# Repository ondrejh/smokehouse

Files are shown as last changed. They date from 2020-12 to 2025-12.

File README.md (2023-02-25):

# SmokeHouse

The IOT smokehouse thermometer using standard web server as the interface.

## Thermometer HW

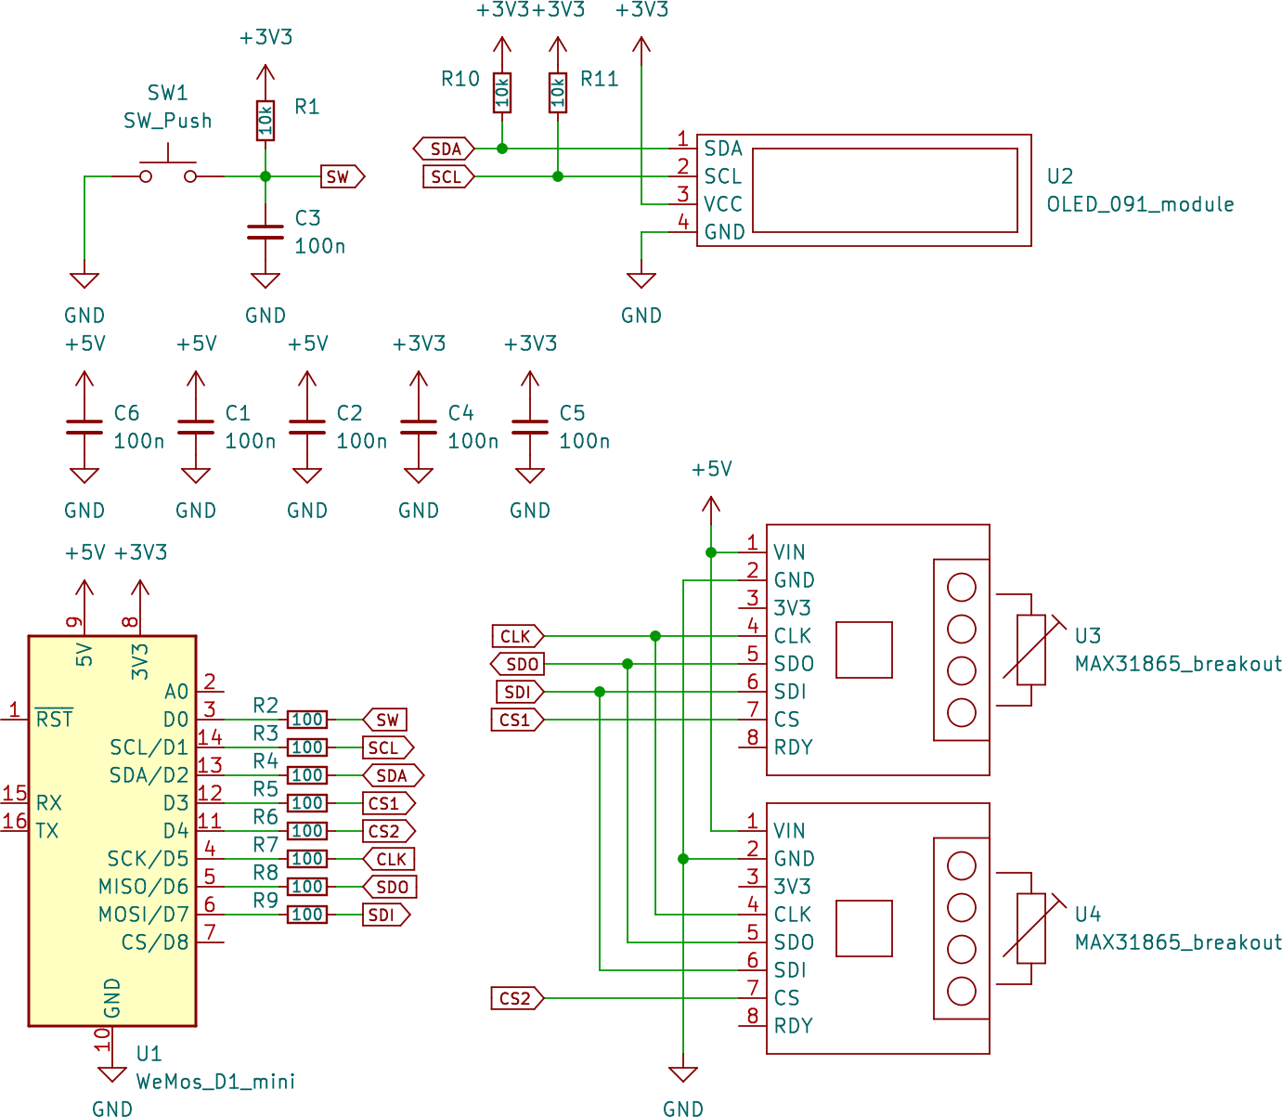
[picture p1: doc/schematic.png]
schematic

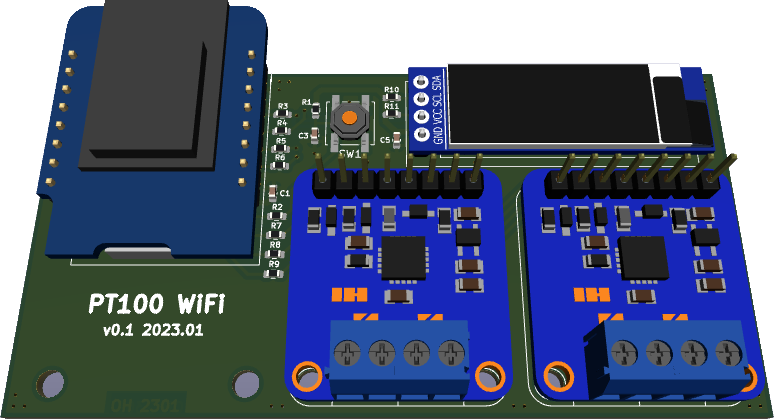
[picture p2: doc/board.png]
board


## DB scheme ##

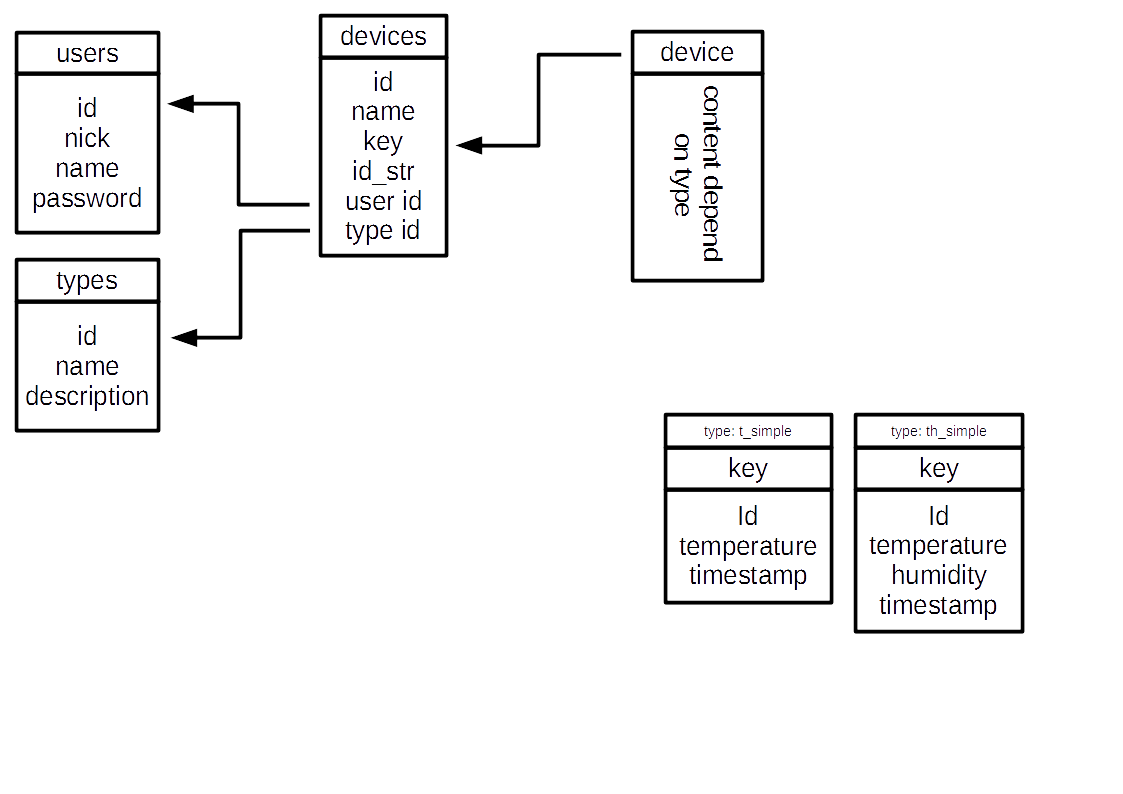
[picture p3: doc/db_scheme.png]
Database scheme


## Next steps (HW / FW) ##

- [X] use device registration (unique id, key)
- [X] add the second thermocoupler
- [X] draw schematic
- [X] design pcb
- [ ] oversampling
- [ ] assemble prototypes

## Next steps (WEBI) ##

- [X] limit data table length
- [X] keep time distances between rows
- [ ] consolidate folders
- [ ] build better local webi
- [ ] build better server webi

## Next steps (all)

- [ ] update docu

## Install LAMP ##

https://gist.github.com/ondrejh/c1df59c4e6e8c8cb88a95b12bdac447b#file-lamp_install-md

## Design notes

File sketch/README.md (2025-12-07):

# Compile and flash using arduino-cli

## Install arduino-cli

```
curl -fsSL https://raw.githubusercontent.com/arduino/arduino-cli/master/install.sh | sudo sh
```

## Compile

Compile **device** sketch using arduino-cli. Target board esp8266 **wemos d1 mini**. Output directory **build**.

```
arduino-cli compile --fqbn esp8266:esp8266:d1_mini --output-dir build device
```

## Flash

```
arduino-cli upload --fqbn esp8266:esp8266:d1_mini -p /dev/ttyUSB0 --input-file build/device.ino.bin
```

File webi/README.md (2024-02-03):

# Files

## Tree

|
|--- inc
|    |--- bootstrap.php
|    |--- config.php
|
|--- thing.php

## Description

inc/config.php: configuration, mainly DB credentials
inc/bootstrap.php: include files

thing.php: the endpoint for data exchange of iot devices

# Database

create database restapi;
use restapi;
create table `things` (`id` bigint(20) unsigned NOT NULL AUTO_INCREMENT, `name` varchar(60) collate utf8mb4_unicode_ci NOT NULL DEFAULT '', `key` varchar(100) collate utf8mb4_unicode_ci NOT NULL DEFAULT '', `data` JSON, PRIMARY KEY(`id`));
insert into things(`name`, `key`) values('test1234', '123456');

# Sources

[How to Build a Simple REST API in PHP](code.tutsplus.com/how-to-build-a-simple-rest-api-in-php--cms-37000t)
[How to Create Simple Rest API in PHP Framework: A Foundation Blueprint](boltic.io/blog/rest-api-in-php-framework)

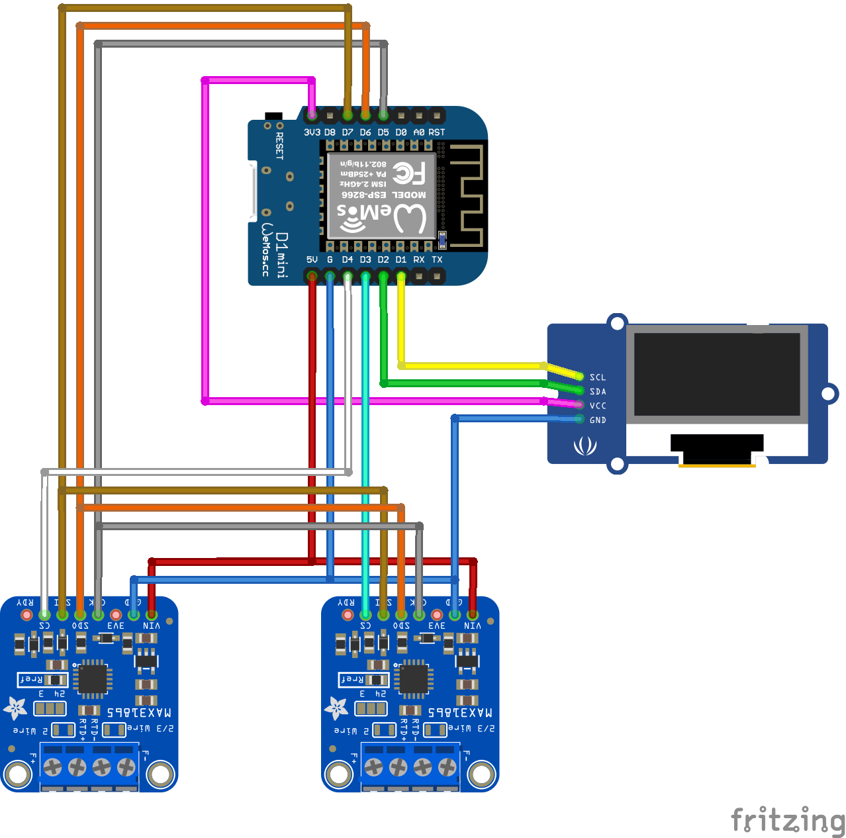
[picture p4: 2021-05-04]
doc/Udirna_2xPT100_bb.png

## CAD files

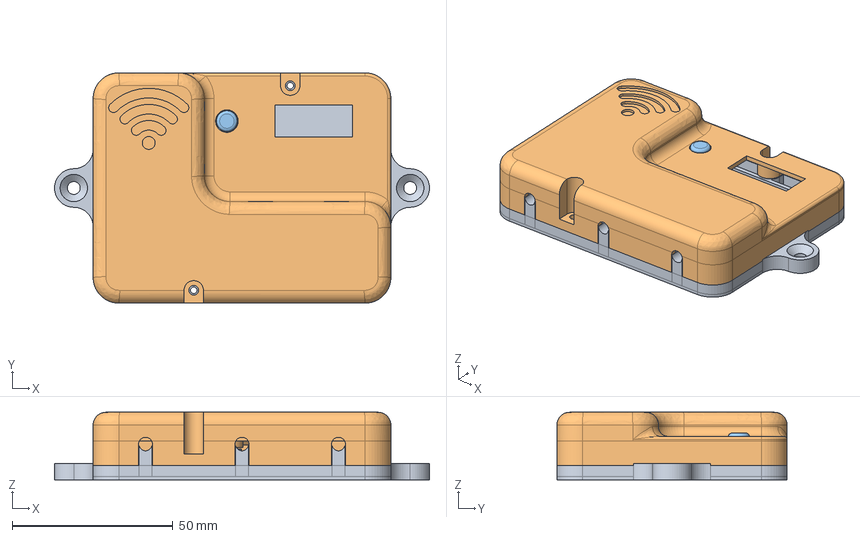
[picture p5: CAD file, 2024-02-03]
models/case.FCStd
116.6 x 71.6 x 21.0 mm
bottom
top
button

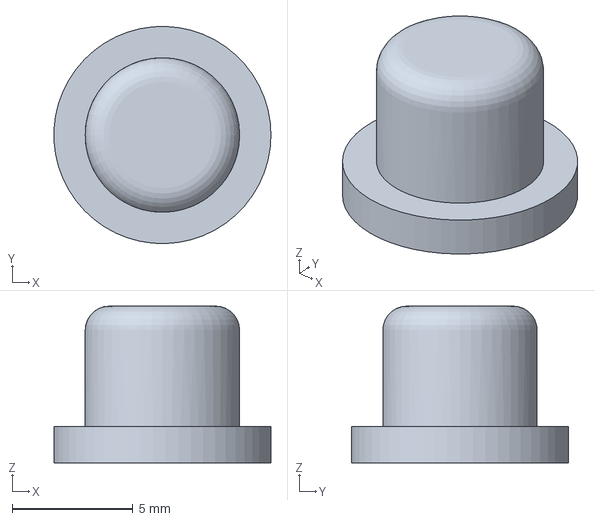
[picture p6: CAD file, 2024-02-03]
models/case-button.3mf
8.99 x 9.00 x 6.50 mm

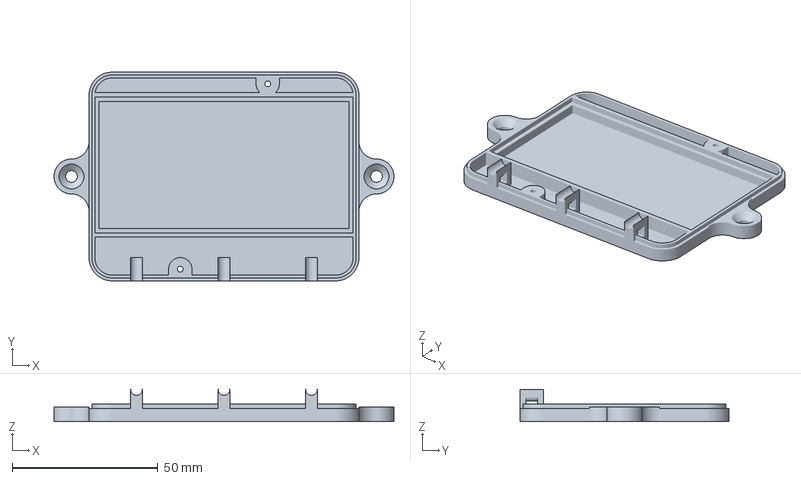
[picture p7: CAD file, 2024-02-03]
models/case-bottom.3mf
116.6 x 71.6 x 11.0 mm

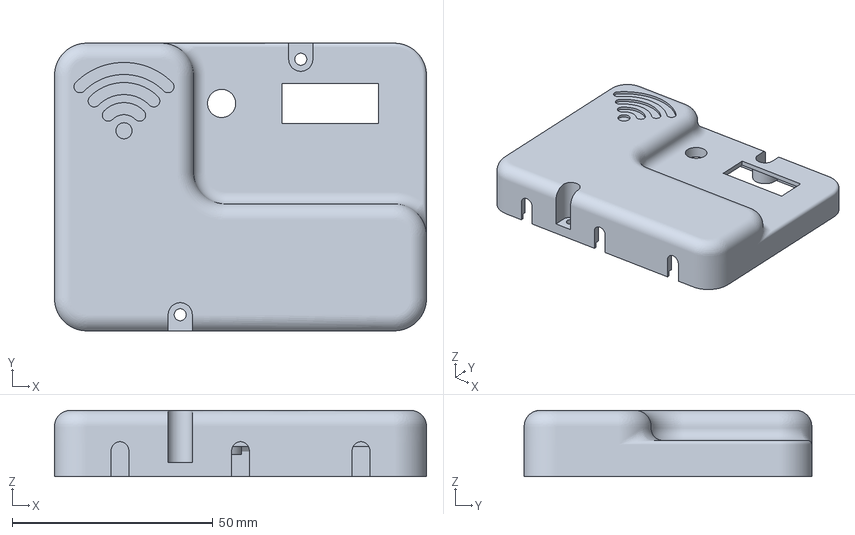
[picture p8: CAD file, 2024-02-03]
models/case-top.3mf
92.6 x 71.6 x 16.5 mm

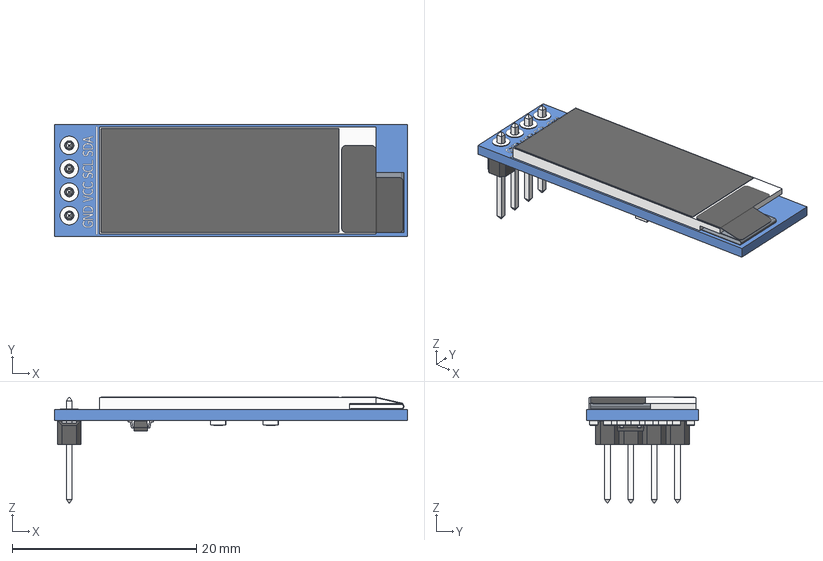
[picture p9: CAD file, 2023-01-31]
models/OLED_0.91_128x32.stp
38.3 x 12.1 x 11.5 mm
OLED_0.91_128x32
Pin Header 4 x 1 TH 2.54mm Pitch
RESC-0603 x 13
2SD0601A

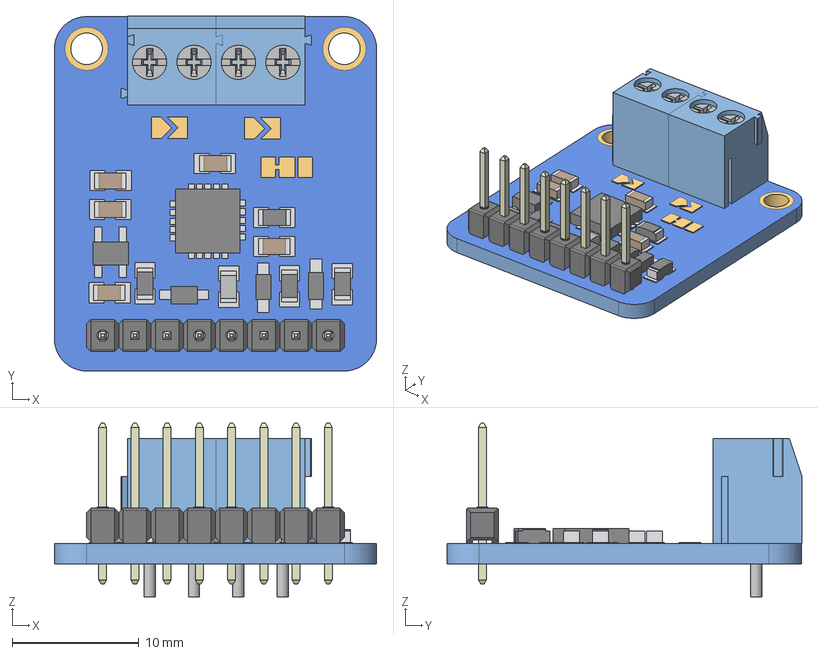
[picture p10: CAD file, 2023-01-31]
models/MAX31865.stp
25.4 x 28.0 x 13.7 mm
plytka
Pin Header 1x4 TH Pitch 2.54mm x 2
TE_1776275-2 x 2

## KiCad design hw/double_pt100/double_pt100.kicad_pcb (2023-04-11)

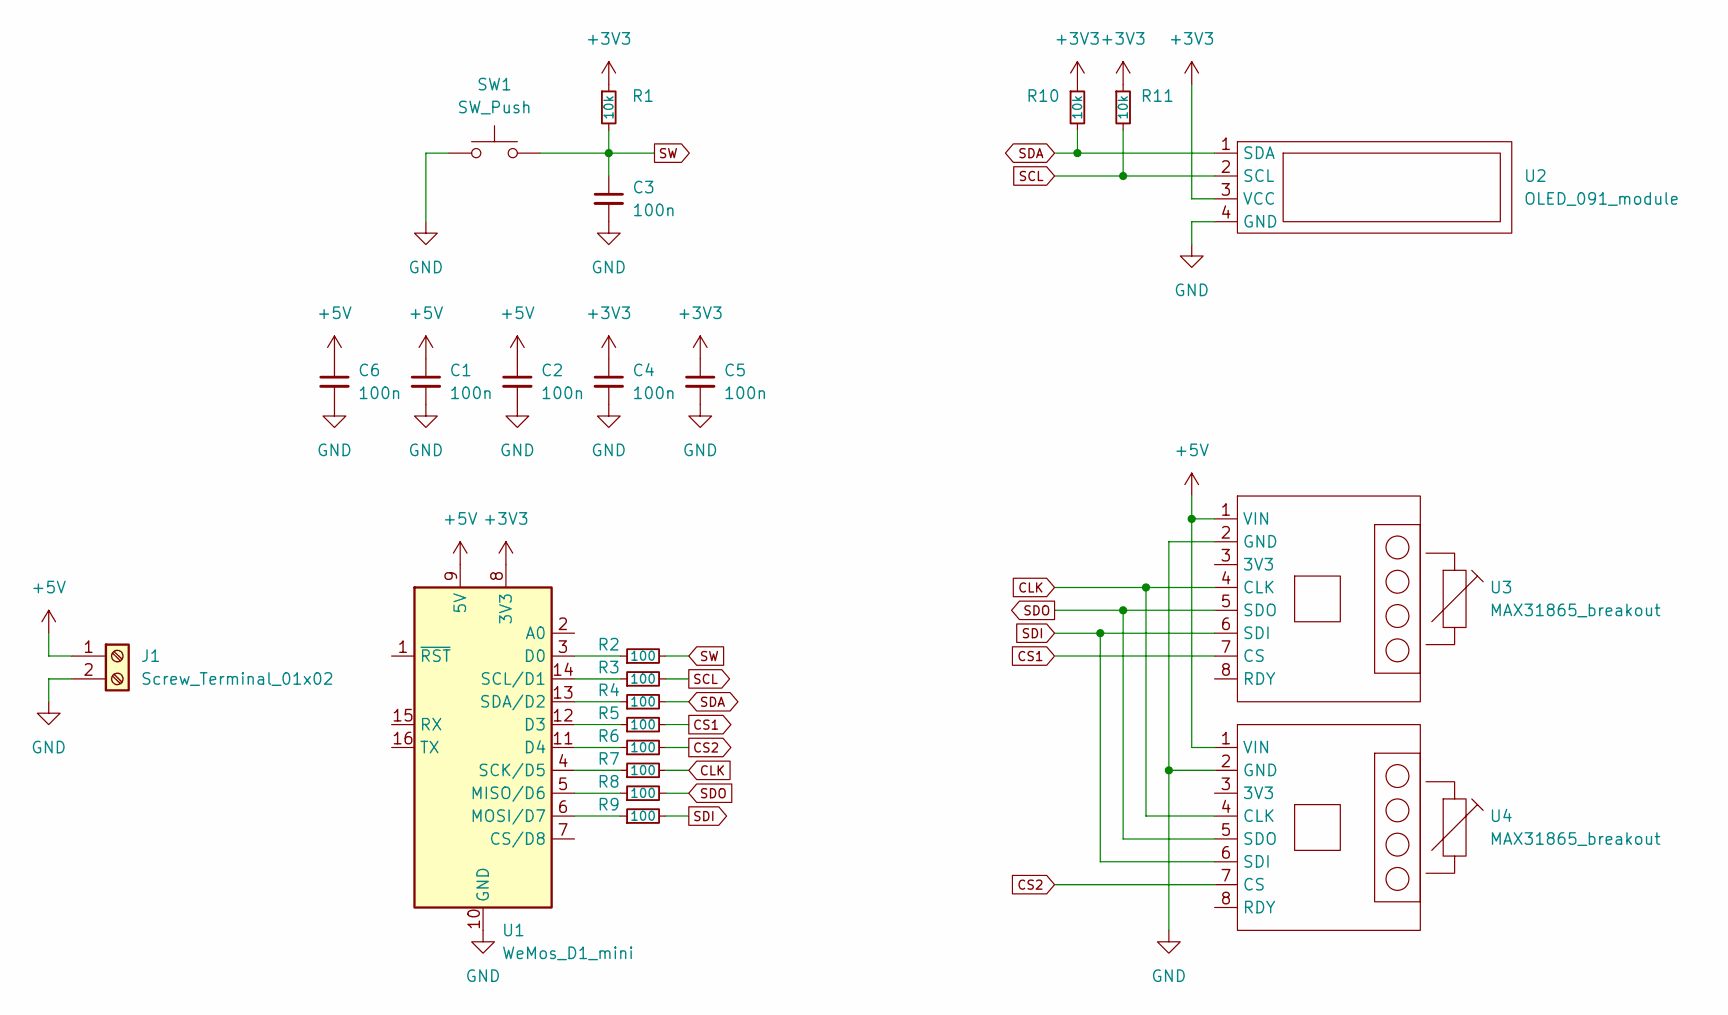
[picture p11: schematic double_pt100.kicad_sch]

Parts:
C1, C2, C3, C4, C5, C6: 100n; C_0603_1608Metric
J1: Screw_Terminal_01x02; TerminalBlock_Phoenix_PT-1,5-2-3.5-H_1x02_P3.50mm_Horizontal
R1, R10, R11: 10k; R_0603_1608Metric
R2, R3, R4, R5, R6, R7, R8, R9: 100; R_0603_1608Metric
SW1: SW_Push; SW_Push_1P1T_NO_CK_KSC6xxJ
U1: WeMos_D1_mini; WEMOS_D1_mini_light
U2: OLED_091_module
U3, U4: MAX31865_breakout; MAX31865_module

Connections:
+3V3: C4.1, C5.1, R1.1, R10.1, R11.1, U1.8 (3V3), U2.3 (VCC)
+5V: C1.1, C2.1, C6.1, J1.1, U1.9 (5V), U3.1 (VIN), U4.1 (VIN)
CLK: R7.2, U3.4 (CLK), U4.4 (CLK)
CS1: R5.2, U3.7 (CS)
CS2: R6.2, U4.7 (CS)
GND: C1.2, C2.2, C3.2, C4.2, C5.2, C6.2, J1.2, SW1.1, U1.10 (GND), U2.4 (GND), U3.2 (GND), U4.2 (GND)
unnamed: R2.1, U1.3 (D0)
unnamed: R3.1, U1.14 (SCL/D1)
unnamed: R4.1, U1.13 (SDA/D2)
unnamed: R5.1, U1.12 (D3)
unnamed: R6.1, U1.11 (D4)
unnamed: R7.1, U1.4 (SCK/D5)
unnamed: R8.1, U1.5 (MISO/D6)
unnamed: R9.1, U1.6 (MOSI/D7)
SCL: R3.2, R11.2, U2.2 (SCL)
SDA: R4.2, R10.2, U2.1 (SDA)
SDI: R9.2, U3.6 (SDI), U4.6 (SDI)
SDO: R8.2, U3.5 (SDO), U4.5 (SDO)
SW: C3.1, R1.2, R2.2, SW1.2

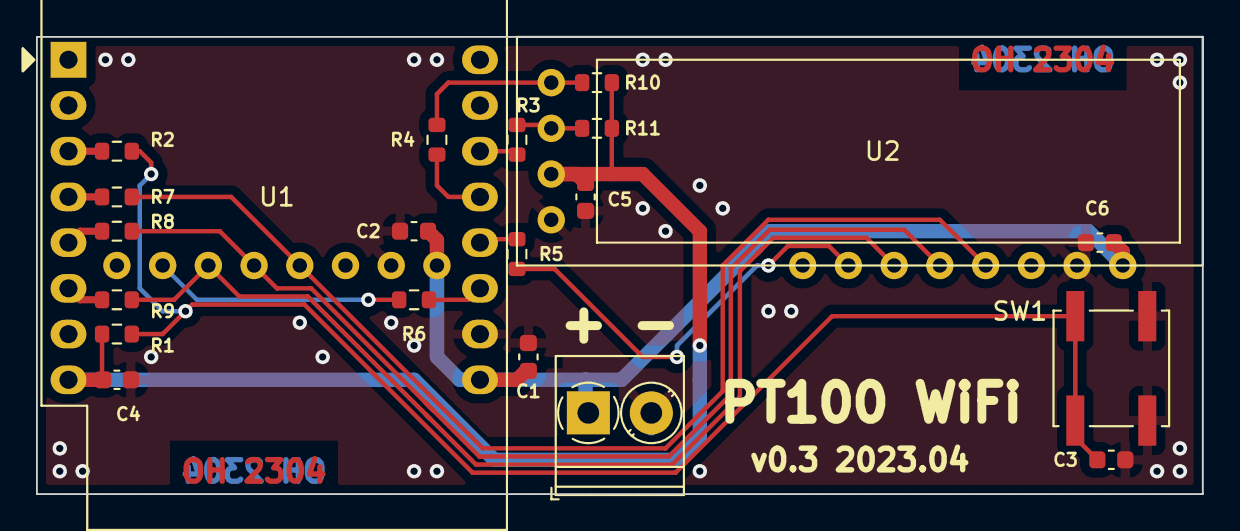
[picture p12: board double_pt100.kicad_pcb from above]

Board: 2 copper layers, 64.8 x 25.4 mm, 23 parts (0 on the bottom side), 19 nets.

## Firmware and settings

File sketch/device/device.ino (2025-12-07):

#include <ESP8266WiFi.h>
#include <WiFiClient.h>
#include <ESP8266WebServer.h>
#include <ESP8266mDNS.h>

#include <ESP8266HTTPClient.h>
#include <PubSubClient.h>

#include <EEPROM.h>

#include <Adafruit_MAX31865.h>

#include "button.h"
#include "webi.h"

#define TEMP_READ_PERIOD_MS 5000
#define DISPLAY_CYCLE_PERIOD_MS 10000
#define BUTTON_PRESS_CYCLE_PAUSE_MS 15000
#define SERVER_SEND_PERIOD_MS 15000
#define MQTT_SEND_PERIOD_MS 5000

#define AP_PASSWORD "temPr321"
IPAddress ap_ip(192,168,42,1);
IPAddress ap_mask(255,255,255,0);

#define SSID_STR_MAX 32
#define PWD_STR_MAX 16

char ssid[SSID_STR_MAX + 1];// = STASSID;
char password[PWD_STR_MAX];// = STAPSK;

char disp_ssid[32];
IPAddress disp_ip;

ESP8266WebServer server(80);

const int led = 13;
const int btnPin = 16;

int temp[2];
bool valid[2];
uint32_t uptim = 0;

//String key = SECRET_KEY;
char idstr[16] = "";

#define EEPROM_SIZE 1024

// configuration data
#define EEPROM_CONF_ADDR 0
#define URL_STR_MAX 128
#define CAPT_STR_MAX 32
#define IP_STR_MAX 32
typedef struct {
  char ssid[SSID_STR_MAX + 1];
  char pwd[PWD_STR_MAX + 1];
  char url[URL_STR_MAX + 1];
  char key[PWD_STR_MAX + 1];
  char capt[CAPT_STR_MAX + 1];
  char mqtt_ip[IP_STR_MAX + 1];
  char mqtt_topic[URL_STR_MAX + 1];
  char mqtt_user[CAPT_STR_MAX + 1];
  char mqtt_pwd[PWD_STR_MAX + 1];
} config_t;

config_t conf;

// home assistant mqtt
const int MQTT_PORT = 1883;

// Use software SPI: CS, DI, DO, CLK
//Adafruit_MAX31865 thermo = Adafruit_MAX31865(D8, D7, D6, D5); // 10k pulldown on D8
Adafruit_MAX31865 thermo1 = Adafruit_MAX31865(2, 13, 12, 14);
Adafruit_MAX31865 thermo2 = Adafruit_MAX31865(0, 13, 12, 14);

Button btn = Button(btnPin);
bool ap_mode = false;
bool server_status = false;
bool mqtt_status = false;

WiFiClient client;
WiFiClientSecure clientSecure;

PubSubClient mqttClient(client);
IPAddress brokerIP;

void mqtt_reconnect() {
  // MQTT reconnect loop
  if (!mqttClient.connected()) {
    Serial.print("Connecting to MQTT... ");

    // CONNECT WITH USER + PASSWORD
    if (conf.mqtt_user[0]!='\0') {
      //if (mqttClient.connect(idstr, mqttUser, mqttPassword)) {
      if (mqttClient.connect(idstr, conf.mqtt_user, conf.mqtt_pwd)) {
        Serial.println("connected!");
      }
      else {
        Serial.print("failed, rc=");
        Serial.println(mqttClient.state());
      }
    }

    // CONNECT (NO USER)
    else {
      if (mqttClient.connect(idstr)) {
        Serial.println("connected!");
      }
      else {
        Serial.print("failed, rc=");
        Serial.println(mqttClient.state());
      }
    }
  }
}

bool push_data_to_server() {
  if (!ap_mode && (WiFi.status() == WL_CONNECTED) && (conf.url[0] != '\0')) {
    Serial.println(millis());
    Serial.print("POST ");
    Serial.println(conf.url);
    uint32_t tElap = micros();
    
    //WiFiClientSecure client;
    //client.setInsecure();
    HTTPClient http;
    char st1[16], st2[16], sup[16];
    if (valid[0]) {
      int it1 = temp[0] / 10;
      int dt1 = (temp[0] >= 0) ? (temp[0] - it1 * 10) : (-temp[0] + it1 * 10);
      sprintf(st1, "%d.%d", it1, dt1);
    }
    else {
      sprintf(st1, "null");
    }
    if (valid[1]) {
      int it2 = temp[1] / 10;
      int dt2 = (temp[1] >= 0) ? (temp[1] - it2 * 10) : (-temp[1] + it2 * 10);
      sprintf(st2, "%d.%d", it2, dt2);
    }
    else {
      sprintf(st2, "null");
    }
    sprintf(sup, "%d", uptim);
    char post[256];
    sprintf(post, "{\"id\":\"%s\", \"key\":\"%s\", \"data\":{\"temp1\": \"%s\", \"temp2\": \"%s\", \"uptim\": \"%s\"}}", idstr, conf.key, st1, st2, sup);
    http.begin(clientSecure, conf.url);
    http.addHeader("Content-Type", "application/json");
    int httpCode = http.POST(post);
    String payload = http.getString();

    http.end();

    tElap = micros() - tElap;
    Serial.print("TIME ");
    Serial.println(tElap);
    Serial.print("DATA ");
    Serial.println(post);
    Serial.print(httpCode);
    Serial.print(" ");
    Serial.println(payload);

    if (httpCode == 200) {
      //Serial.println("True");
      return true;
    }
  }
  return false;
}

void setup(void) {
  Serial.begin(115200);
  delay(300);
  Serial.println();

  pinMode(led, OUTPUT);
  digitalWrite(led, 0);

  thermo1.begin(MAX31865_3WIRE);
  thermo2.begin(MAX31865_3WIRE);

  // init eeprom data
  init_eeprom(EEPROM_SIZE);
  if (eeload(EEPROM_CONF_ADDR, &conf, sizeof(conf)) < 0) {
    Serial.println("No valid configuration in EEPROM. Using default.");
    conf.ssid[0] = 0;
    conf.pwd[0] = 0;
    conf.url[0] = 0;
    conf.key[0] = 0;
    strcpy(conf.capt, "Teploměr\0");
    eesave(EEPROM_CONF_ADDR, &conf, sizeof(conf));
    ap_mode = true;
  }
  else {
    if (conf.ssid[0] == 0) {
      Serial.println("WiFi not configured. Start AP mode.");
      ap_mode = true;
    }
  }

  display_init();

  // create device id string
  uint8_t mac[6];
  WiFi.macAddress(mac);
  sprintf(idstr, "Temp%02X%02X%02X", mac[3], mac[4], mac[5]);

  Serial.begin(115200);

  for (int i=0; i<16; i++) {
    btn.poll();
    if (btn.press) {
      ap_mode = true;
      break;
    }
    delay(2);
  }

  if (!ap_mode) {
    WiFi.mode(WIFI_STA);
    WiFi.begin(conf.ssid, conf.pwd);
    Serial.println("");

    // Wait for connection
    display_connecting();
    int cnt = 0;
    while (WiFi.status() != WL_CONNECTED) {
      cnt ++;
      if (cnt > 60) {
        ap_mode = true;
        break;
      }
      delay(500);
      Serial.print(".");
    }
    Serial.println("");
    
    if (!ap_mode) {
      strncpy(disp_ssid, conf.ssid, 32);
      disp_ip = WiFi.localIP();
      Serial.print("Connected to ");
      Serial.println(disp_ssid);
      Serial.print("IP address: ");
      Serial.println(disp_ip);//WiFi.localIP());

      // Resolve broker hostname
      if (conf.mqtt_ip[0] != '\0') {
        //if (WiFi.hostByName("homeassistant.local", brokerIP)) {
        if (WiFi.hostByName(conf.mqtt_ip, brokerIP)) {
          Serial.print("MQTT server: ");
          Serial.print(brokerIP);
          Serial.print(":");
          Serial.println(MQTT_PORT);
          mqttClient.setServer(brokerIP, MQTT_PORT);
        } else {
          Serial.println("Resolve failed");
        }
      }
    }
    else {
      Serial.print("Can't connect to ");
      Serial.println(conf.ssid);
    }

  }
  if (ap_mode) {
    display_apmode();
    Serial.println("Configuring access point.");
    /* You can remove the password parameter if you want the AP to be open. */
    strncpy(disp_ssid, idstr, 32);
    WiFi.softAPConfig(ap_ip, ap_ip, ap_mask);
    WiFi.softAP(idstr, AP_PASSWORD);

    disp_ip = WiFi.softAPIP();
    Serial.print("AP IP address: ");
    Serial.println(disp_ip);
  }

  if (MDNS.begin(idstr)) {
    Serial.println("MDNS responder started");
  }

  server.on("/", handleRoot);
  server.on("/index.html", handleRoot);
  server.on(config_name, handleConfig);
  server.on("/data.json", handleData);
  server.on("/config.json", handleConf);
  server.on("/set.php", HTTP_POST, handleSet);
  server.on(favicon_name, handleFavicon);
  //server.on(style_name, handleStyle);
  //server.on(script_name, handleScript);
  server.onNotFound(handleNotFound);
  server.begin();
  Serial.println("HTTP server started");

  clientSecure.setInsecure();
}

void loop(void) {
  uint32_t now = millis();
  static bool refresh = false;

  static uint32_t uptim_ms;
  while ((now - uptim_ms) > 1000) {
    uptim_ms += 1000;
    uptim ++;
  }
  
  server.handleClient();
  //MDNS.update();

  btn.poll();
  if (btn.press) Serial.println("Pressed");
  if (btn.release) Serial.println("Released");

  static uint32_t tempT = TEMP_READ_PERIOD_MS;
  static int tempCh = 0;
  if ((now - tempT) >= TEMP_READ_PERIOD_MS) {
    int t;
    if (read_temperature(tempCh, &t) == 0) {
      temp[tempCh] = t;
      valid[tempCh] = true;
    }
    else {
      valid[tempCh] = false;
    }
    tempCh ++;
    if (tempCh >= 2) {
      tempT = now;
      tempCh = 0;
    }
  }

  static uint32_t dispT = 0;
  static int disp = 0;
  static uint32_t period = DISPLAY_CYCLE_PERIOD_MS;
  if ( ((now - dispT) >= period) || btn.press || refresh) {
    dispT = now;
    period = btn.press ? BUTTON_PRESS_CYCLE_PAUSE_MS : DISPLAY_CYCLE_PERIOD_MS;

    switch (disp) {
      case 0:
        display_wifi(disp_ssid, disp_ip);
        break;
      case 1:
        display_temp(0);
        break;
      case 2:
        display_temp(1);
        break;
      default:
        break;
    }
    
    if (!refresh) {
      disp ++;
      disp %= 3;
    }
    refresh = false;
  }

  if (!ap_mode) {
    if (conf.url[0] != '\0') {
      static uint32_t pushT = now;
      if ((now - pushT) >= SERVER_SEND_PERIOD_MS) {
        if (conf.url[0] != '\0') {
          display_transfer();
          server_status = push_data_to_server();
          refresh = true;
        }
        pushT = millis();
      }
    }
    else {
      server_status = false;
    }

    if (conf.mqtt_ip[0] != '\0') {
      static uint32_t pushM = now;
      if ((now - pushM) >= MQTT_SEND_PERIOD_MS) {
        if (!mqttClient.connected()) {
          mqtt_reconnect();
        }
        if (mqttClient.connected()) {
          mqtt_status = true;
          String t1 = temp2string(temp[0], valid[0]);
          String t2 = temp2string(temp[1], valid[1]);

          // Create JSON payload
          //String json = "{";
          //json += "\"t1\": ";
          //json += t1);
          //json += ",\"t2\": ";
          //json += t2);
          //json += "}";

          // publish json
          //mqttClient.publish(mqttTopic, json.c_str());

          Serial.print("Publish: ");
          //Serial.println(json);

          // publish
          mqttClient.publish(((String)conf.mqtt_topic + "/t1").c_str(), t1.c_str());
          mqttClient.publish(((String)conf.mqtt_topic + "/t2").c_str(), t2.c_str());
          mqttClient.loop();

          Serial.print(t1);
          Serial.print(", ");
          Serial.println(t2);
        }
        else {
          mqtt_status = false;
        }
        pushM = millis();
      }
    }
    else {
      mqtt_status = false;
    }
  } // !ap_mode
  else {
    server_status = false;
    mqtt_status = false;
  }
}

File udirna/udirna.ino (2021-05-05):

/*
    DONE: 
  1) NTP client
  2) Connect display
  3) Connect sensor
  4) Show IP and time
  5) Show temperature

    TODO: 
  6) Html temperature
    a) install LAMP (local testing)
    b) create input form
    c) send data
    d) test data
  7) Connect second sensor

  test db:
    database uzeniTest
    user udirna
    password udirna123
*/

#include <Wire.h>
#include <Adafruit_GFX.h>
#include <Adafruit_SSD1306.h>

#include <ESP8266WiFi.h>
#include <WiFiClient.h>
#include <ESP8266WebServer.h>
#include <ESP8266mDNS.h>

#include <ESP8266HTTPClient.h>

#include <NTPClient.h>
#include <WiFiUdp.h>

#include <Adafruit_MAX31865.h>

#include "password.h"

#ifndef STASSID
#define STASSID "wifi_ssid"
#define STAPSK  "wifi_password"
#define KEY "123456"
#define DATAIN "http://www.foo.bar/baz.php"
#endif

const long utcOffsetInSeconds = 7200;

const char *ssid = STASSID;
const char *password = STAPSK;

int temp[2];

// display
#define SCREEN_WIDTH 128 // OLED display width, in pixels
#define SCREEN_HEIGHT 32 // OLED display height, in pixels
#define OLED_RESET     -1 // Reset pin # (or -1 if sharing Arduino reset pin)
Adafruit_SSD1306 display(SCREEN_WIDTH, SCREEN_HEIGHT, &Wire, OLED_RESET);

ESP8266WebServer server(80);

// Define NTP Client to get time
WiFiUDP ntpUDP;
NTPClient timeClient(ntpUDP, "pool.ntp.org", utcOffsetInSeconds);

// The value of the Rref resistor. Use 430.0 for PT100 and 4300.0 for PT1000
#define RREF      430.0
// The 'nominal' 0-degrees-C resistance of the sensor
// 100.0 for PT100, 1000.0 for PT1000
#define RNOMINAL  100.0

char idstr[16] = "";

// Use software SPI: CS, DI, DO, CLK
//Adafruit_MAX31865 thermo = Adafruit_MAX31865(D8, D7, D6, D5); // 10k pulldown on D8
Adafruit_MAX31865 thermo1 = Adafruit_MAX31865(2, 13, 12, 14);
Adafruit_MAX31865 thermo2 = Adafruit_MAX31865(0, 13, 12, 14);

const int led = 13;

void handleRoot() {
  digitalWrite(led, 1);
  char temp[400];
  int sec = millis() / 1000;
  int min = sec / 60;
  int hr = min / 60;

  snprintf(temp, 400,

"<html>\
  <head>\
    <meta http-equiv='refresh' content='5'/>\
    <title>ESP8266 Demo</title>\
    <style>\
      body { background-color: #cccccc; font-family: Arial, Helvetica, Sans-Serif; Color: #000088; }\
    </style>\
  </head>\
  <body>\
    <h1>Hello from ESP8266!</h1>\
    <p>Uptime: %02d:%02d:%02d</p>\
    <p>Time: %2d:%02d:%02d</p>\
  </body>\
</html>",

           hr, min % 60, sec % 60, timeClient.getHours(), timeClient.getMinutes(), timeClient.getSeconds()
          );
  server.send(200, "text/html", temp);
  digitalWrite(led, 0);
}

void handleNotFound() {
  digitalWrite(led, 1);
  String message = "File Not Found\n\n";
  message += "URI: ";
  message += server.uri();
  message += "\nMethod: ";
  message += (server.method() == HTTP_GET) ? "GET" : "POST";
  message += "\nArguments: ";
  message += server.args();
  message += "\n";

  for (uint8_t i = 0; i < server.args(); i++) {
    message += " " + server.argName(i) + ": " + server.arg(i) + "\n";
  }

  server.send(404, "text/plain", message);
  digitalWrite(led, 0);
}

void setup(void) {
  Serial.begin(115200);

  thermo1.begin(MAX31865_3WIRE);
  thermo2.begin(MAX31865_3WIRE);

  // SSD1306_SWITCHCAPVCC = generate display voltage from 3.3V internally
  if(!display.begin(SSD1306_SWITCHCAPVCC, 0x3C))// Address 0x3C for 128x32
    Serial.println(F("SSD1306 allocation failed"));

  // show initial display buffer contents on the screen
  display.display();

  pinMode(led, OUTPUT);
  digitalWrite(led, 0);

  WiFi.mode(WIFI_STA);
  WiFi.begin(ssid, password);
  Serial.println("");

  // Wait for connection
  while (WiFi.status() != WL_CONNECTED) {
    delay(500);
    Serial.print(".");
  }

  Serial.println("");
  Serial.print("Connected to ");
  Serial.println(ssid);
  Serial.print("IP address: ");
  Serial.println(WiFi.localIP());

  if (MDNS.begin("esp8266")) {
    Serial.println("MDNS responder started");
  }

  server.on("/", handleRoot);
  server.onNotFound(handleNotFound);
  server.begin();
  Serial.println("HTTP server started");
  
  timeClient.begin();

  uint8_t mac[6];
  WiFi.macAddress(mac);
  sprintf(idstr, "d1mini%02X%02X%02X", mac[3], mac[4], mac[5]);

  display_wifi();
}

int read_temperature(uint8_t s) {
  if (s > 1) return 0;
  
  float t;
  uint16_t rtd;
  if (s == 0) {
    rtd = thermo1.readRTD();
    t = thermo1.temperature(RNOMINAL, RREF);
  }
  else {
    rtd = thermo2.readRTD();
    t = thermo2.temperature(RNOMINAL, RREF);
  }

  int it = round(t * 10);

  Serial.print("Temperature ");
  Serial.print(s + 1);
  Serial.print(" ");
  Serial.print(t);
  Serial.println(" C");

  return it;
}

bool push_data_to_server(float t1, float t2) {
  if (WiFi.status() == WL_CONNECTED) {
    HTTPClient http;
    int it1, dt1, it2, dt2;
    it1 = t1 / 10;
    dt1 = t1 - it1 * 10;
    it2 = t2 / 10;
    dt2 = t2 - it2 * 10;
    char post[128];
    //sprintf(post, "key=blablabla&data=%d.%d", it, dt);
    //http.begin("http://192.168.88.230/test/data_input.php");
    //http.addHeader("Content-Type", "application/x-www-form-urlencoded");
    sprintf(post, "{\"key\":\"%s\", \"idstr\":\"%s\", \"data\":[\"%d.%d\", \"%d.%d\"]}", KEY, idstr, it1, dt1, it2, dt2);
    http.begin(DATAIN);
    http.addHeader("Content-Type", "application/json");
    int httpCode = http.POST(post);
    String payload = http.getString();
    http.end();

    Serial.print("POST ");
    Serial.print(post);
    Serial.print(" ");
    Serial.print(it1);
    Serial.print(".");
    Serial.print(dt1);
    Serial.print(" ");
    Serial.print(it2);
    Serial.print(".");
    Serial.print(dt2);
    Serial.print(" ");
    Serial.println(httpCode);
    Serial.println(payload);

    if (payload == "OK")
      return true;
  }
  return false;
}

void loop(void) {
  timeClient.update();
  server.handleClient();
  MDNS.update();

  static uint32_t temp_t = 30001;
  uint32_t now = millis();
  static uint8_t s = 0;
  if ((now - temp_t) > 30000) {
    temp[s] = read_temperature(s++);
    if (s == 2) {
      push_data_to_server(temp[0], temp[1]);
      temp_t = now;
      s = 0;
    }
  }

  static int disp = 1;
  static uint32_t disp_t = 0;
  if ((now - disp_t) > 5000) {
    disp_t = now;
    switch (disp) {
      case 0: // WIFI
        display_wifi();
        disp ++;
      break;
      case 1: // TIME
        display_time();
        disp ++;
      break;
      case 2: // TEMP 1
        display_temp(0);
        disp ++;
      break;
      case 3: // TEMP 2
        display_temp(1);
        disp = 0;
      break;
    }
  }
}

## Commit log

2020-12-15 register device into the database
2020-12-15 list devices
2020-12-16 allow change device name
2020-12-16 new sketch for th simple sensor
2020-12-21 show device form (not finished)
2021-01-22 device viewer
2021-02-19 return last values the device sent
2021-05-04 schematic - not tested
2021-05-04 second sensor
2021-05-05 display temperature source (1 / 2)
2023-01-31 first hw
    [double_pt100.kicad_pcb, double_pt100.kicad_sch]
2023-01-31 layout done
    [MAX31865.stp, OLED_0.91_128x32.stp, double_pt100.kicad_pcb]
2023-02-01 gerbers to order the prototype
    [double_pt100-B_Cu.gbr, double_pt100-B_Mask.gbr, double_pt100-Edge_Cuts.gbr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]
2023-02-03 pcb doc
2023-02-04 button display cycler
2023-02-15 iBOM to ease assembly
2023-02-25 keep time distance between samples
2023-02-25 main sketch renamed to device
2023-02-26 avg 8 samples
2023-02-28 no wifi version of the device sketch
2023-03-11 keg scale device data input
2023-03-12 kegscale device input
2023-03-25 hw version 0.2 with alternative assembly
    [double_pt100.kicad_pcb, double_pt100.kicad_sch]
2023-04-09 evaulate disconnected sensor or broken adc, send null in the case
    [device.ino, display.ino, handlers.ino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]
2023-04-09 no wifi alternative hw extra directory
    [double_pt100.kicad_pcb, double_pt100.kicad_sch]
2023-04-09 dir renamed
    [double_pt100.kicad_pcb, double_pt100.kicad_sch]
2023-04-09 yet another dir rename
    [double_pt100-B_Cu.gbr, double_pt100-B_Mask.gbr, double_pt100-Edge_Cuts.gbr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]
2023-04-11 hw version mini
    [double_pt100-B_Cu.gbr, double_pt100-B_Mask.gbr, double_pt100-Edge_Cuts.gbr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]
2025-12-07 mqtt settings implemented in device
2026-01-14 debug - temperature display function
